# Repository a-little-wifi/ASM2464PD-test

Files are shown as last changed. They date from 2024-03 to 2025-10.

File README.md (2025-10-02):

# ASM2464PD-test
I wanted to know more about the new Asmedia USB4 chips because I want to make USB-C PCIe stuff.

The ASM2464PD is meant for USB4 (or Thunderbolt 3 and USB3.x too, afaik) to NVMe SSD enclosures, and the ASM2464PDX is meant for USB4/TB to general PCIe devices such as GPUs.  
I've read that the PD one also works for general PCIe devices but it's not officially supported. An AX210 wifi card worked on an ASM2464PD (non-X) enclosure for me, haven't tried GPUs yet.

So anyway I found some sussy data online and made a kicad version of the ASM2464PD pcb footprint and schematic symbol, it's a start to figuring out how to DIY something with these chips. I've got datasheets and reference schematics now so I'm slowly working on making a complete functional replica.  

Current PCB layout is only for fun, differential pairs are not impedance matched yet and there's probably various other issues lol. 

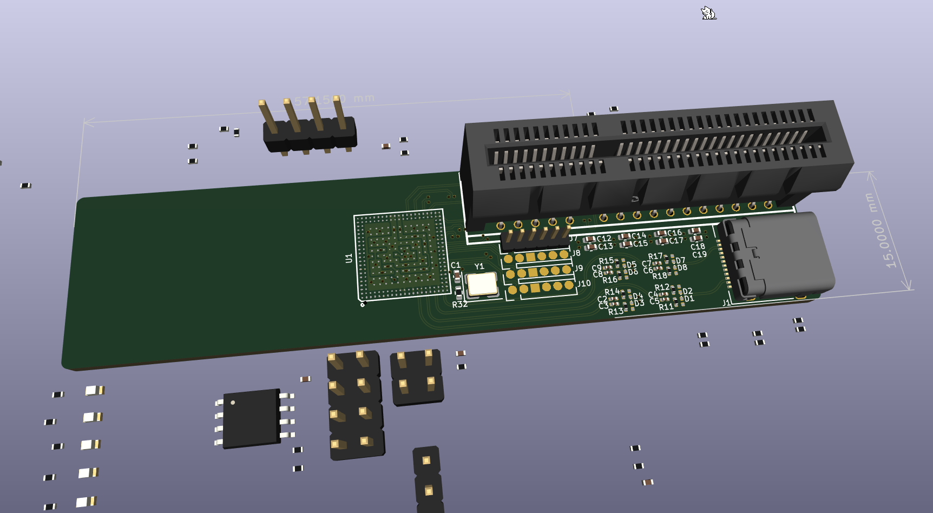
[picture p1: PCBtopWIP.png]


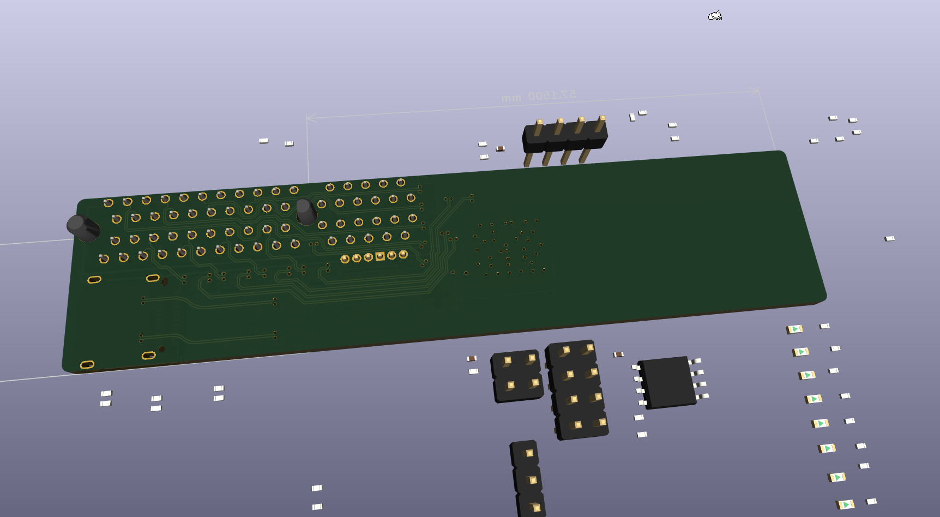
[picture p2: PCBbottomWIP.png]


Random Chinese forum link with datasheet screenshots + bits of a reference schematic: https://blog.csdn.net/weixin_54493972/article/details/127628081

Footprint/symbol reference: https://jlcpcb.com/partdetail/Asmedia-ASM2464PD/C7509569

Detailed images of a board: https://www.reddit.com/r/UsbCHardware/comments/17tjmh4/diy_ultra_compact_usb4thunderbolt_4_ssd_enclosure/

Datasheets and reference schematics: https://files.slop.gay/pub/docs/Asmedia/ASM2464PD-X/

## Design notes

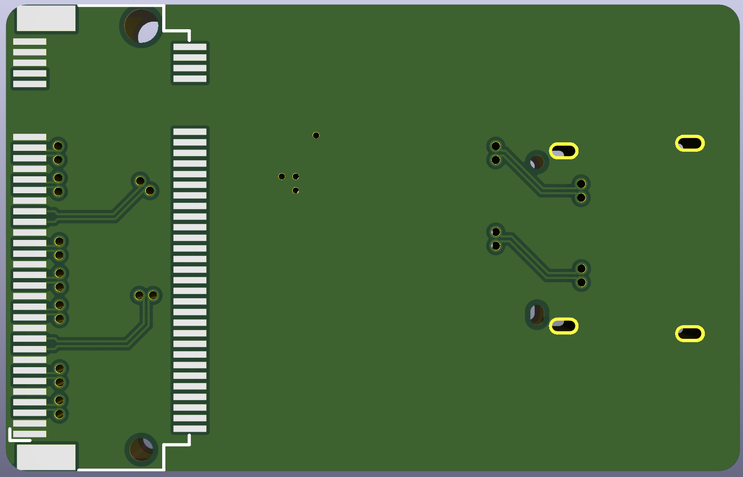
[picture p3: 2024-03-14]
PCBback.png

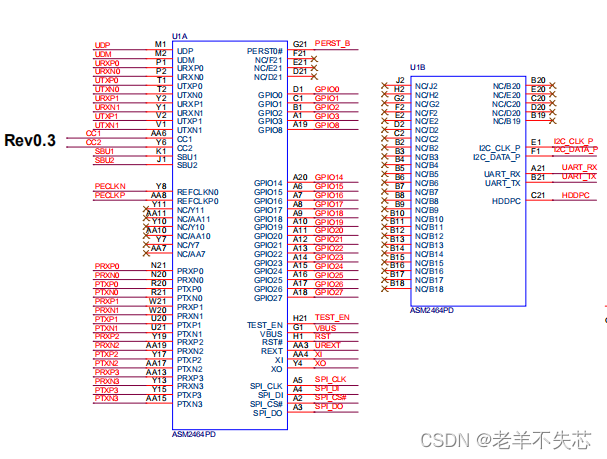
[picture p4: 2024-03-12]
ASM2464pins.png

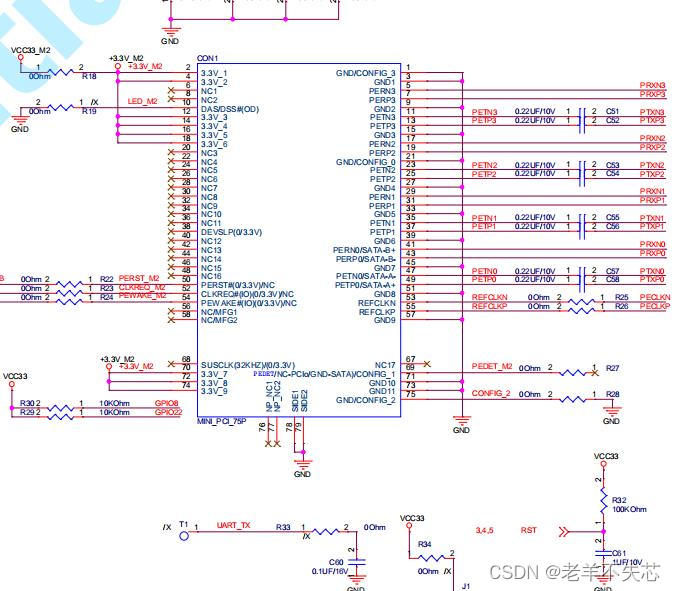
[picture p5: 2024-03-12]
M2pins.jpeg

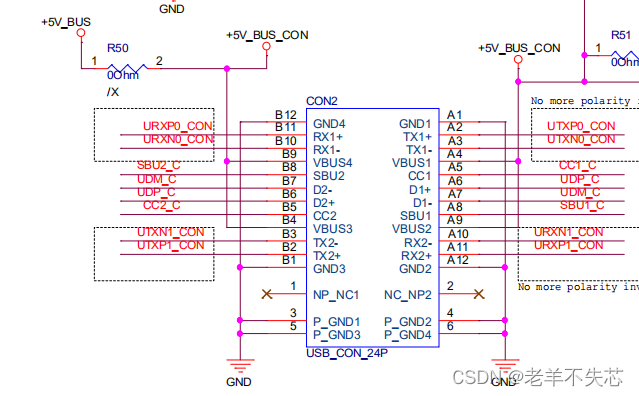
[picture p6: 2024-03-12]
USBCpins.png

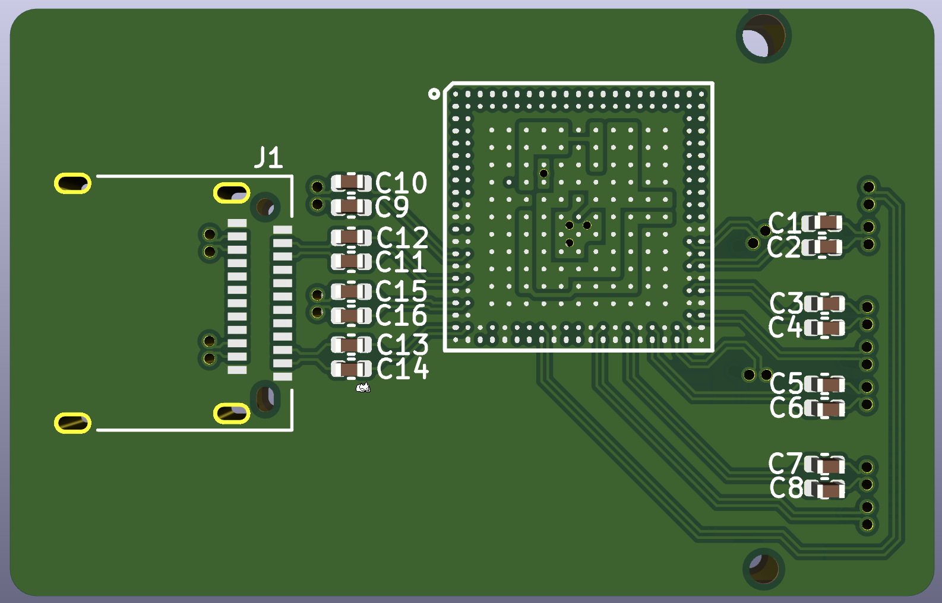
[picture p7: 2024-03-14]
PCBfront.png

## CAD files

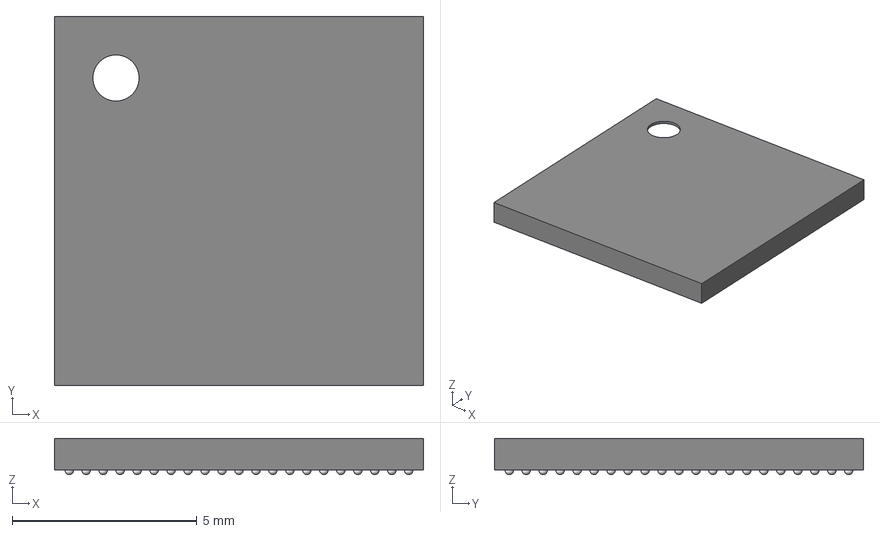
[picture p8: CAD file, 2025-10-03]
asm2464pd-kinda-close-enough.step
10.0 x 10.0 x 0.982 mm
ball x 377

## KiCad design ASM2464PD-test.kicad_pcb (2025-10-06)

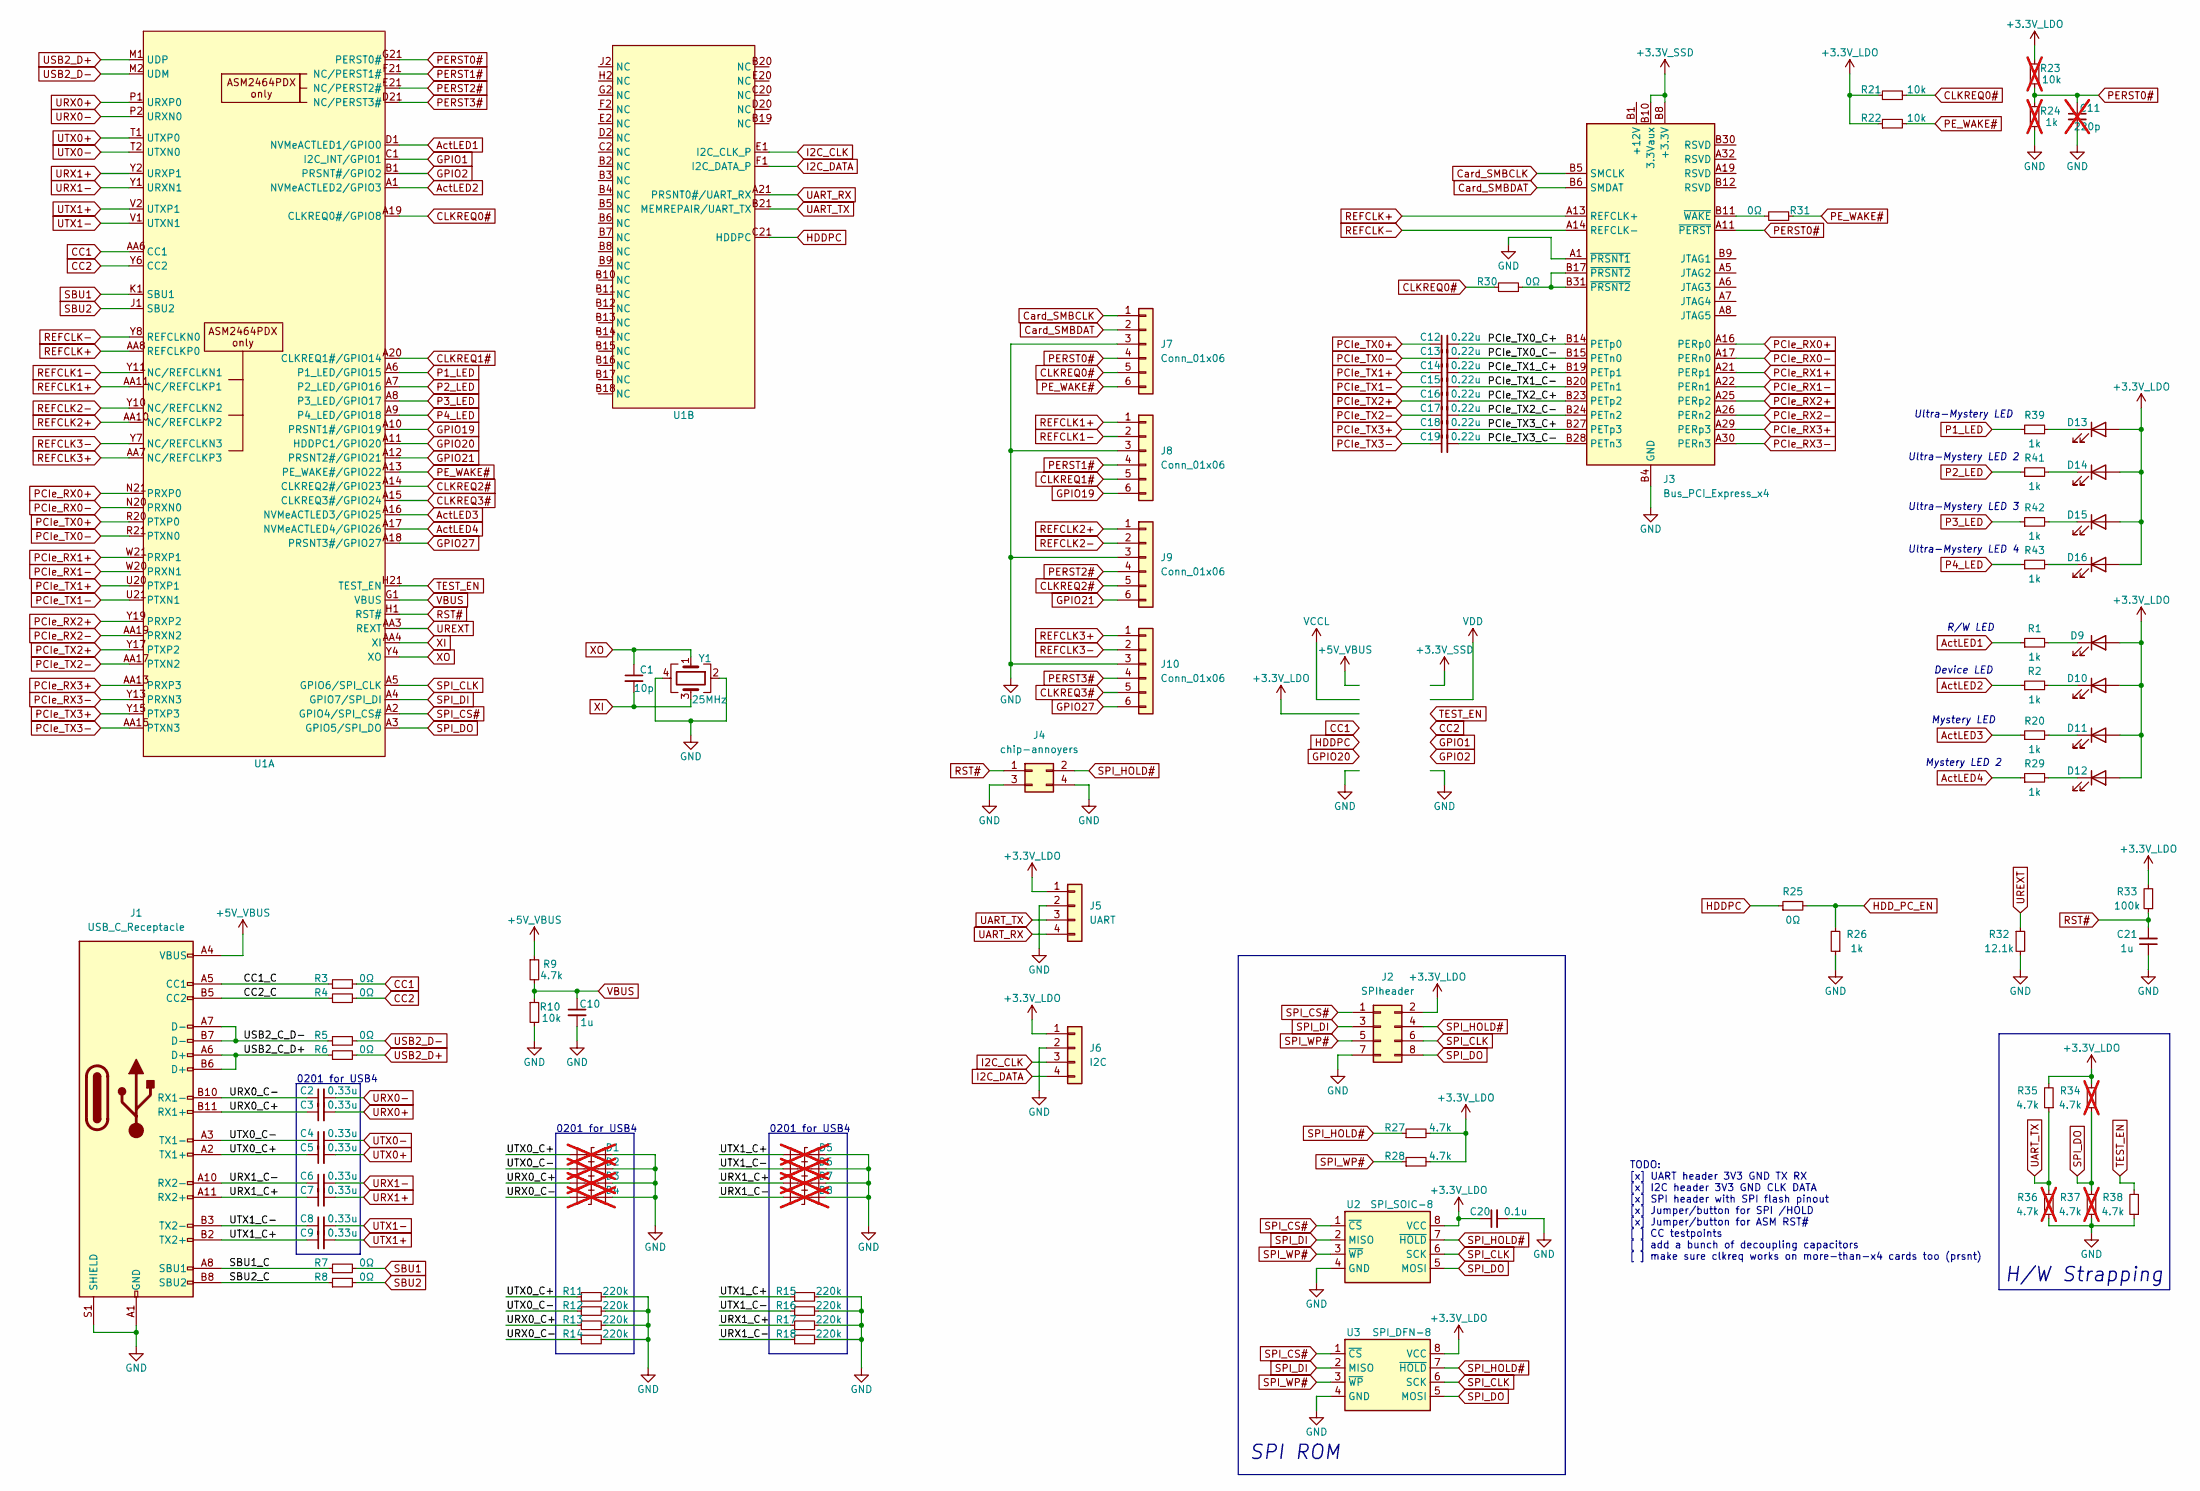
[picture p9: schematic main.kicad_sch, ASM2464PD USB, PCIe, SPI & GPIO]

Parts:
C1: 10p; C_0402_1005Metric
C2, C3, C4, C5, C6, C7, C8, C9: 0.33u; C_0201_0603Metric
C10, C21: 1u; C_0402_1005Metric
C11: 220p; C_0402_1005Metric; not fitted
C12, C13, C14, C15, C16, C17, C18, C19: 0.22u; C_0402_1005Metric
C20: 0.1u; C_0402_1005Metric
D1, D2, D3, D4, D5, D6, D7, D8: D_0201_0603Metric; not fitted
D9, D10, D11, D12, D13, D14, D15, D16: LED_0603_1608Metric
J1: USB_C_Receptacle; USB_C_Receptacle_Amphenol_12401610E4-2A
J2: SPIheader; PinHeader_2x04_P2.54mm_Vertical
J3: Bus_PCI_Express_x4; PCIe_x4_tht_open
J4: chip-annoyers; PinHeader_2x02_P2.54mm_Vertical
J5: UART; PinHeader_1x04_P2.54mm_Vertical
J6: I2C; PinHeader_1x04_P2.54mm_Vertical
J7, J8, J9, J10: Conn_01x06; PinHeader_1x06_P1.27mm_Vertical
R1, R2, R20, R26, R29, R39, R41, R42, R43: 1k; R_0402_1005Metric
R3, R4, R5, R6, R7, R8, R25, R30, R31: 0Ω; R_0402_1005Metric
R9, R27, R28, R35, R38: 4.7k; R_0402_1005Metric
R10, R21, R22: 10k; R_0402_1005Metric
R11, R12, R13, R14, R15, R16, R17, R18: 220k; R_0201_0603Metric
R23: 10k; R_0402_1005Metric; not fitted
R24: 1k; R_0402_1005Metric; not fitted
R32: 12.1k; R_0402_1005Metric
R33: 100k; R_0402_1005Metric
R34, R36, R37: 4.7k; R_0402_1005Metric; not fitted
U1: ASM2464PD
U2: SPI_SOIC-8; SOIC-8_5.3x5.3mm_P1.27mm
U3: SPI_DFN-8; DFN-8-1EP_3x2mm_P0.5mm_EP1.3x1.5mm
Y1: 25MHz; Crystal_SMD_3225-4Pin_3.2x2.5mm

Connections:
+3.3V_LDO: C20.1, D9.2 (A), D10.2 (A), D11.2 (A), D12.2 (A), D13.2 (A), D14.2 (A), D15.2 (A), D16.2 (A), J2.2, J5.1, J6.1, R21.1, R22.1, R23.1, R27.2, R28.2, R33.2, R34.2, R35.2, U2.8 (VCC), U3.8 (VCC); also elsewhere on the board
+3.3V_SSD: J3.A9 (+3.3V), J3.A10 (+3.3V), J3.B8 (+3.3V), J3.B10 (3.3Vaux)
+5V_VBUS: J1.A4 (VBUS), J1.A9 (VBUS), J1.B4 (VBUS), J1.B9 (VBUS), R9.1
/Main/CC1_C: J1.A5 (CC1), R3.1
/Main/CC2_C: J1.B5 (CC2), R4.1
/Main/PCIe_TX0_C+: C12.2, J3.B14 (PETp0)
/Main/PCIe_TX0_C-: C13.2, J3.B15 (PETn0)
/Main/PCIe_TX1_C+: C14.2, J3.B19 (PETp1)
/Main/PCIe_TX1_C-: C15.2, J3.B20 (PETn1)
/Main/PCIe_TX2_C+: C16.2, J3.B23 (PETp2)
/Main/PCIe_TX2_C-: C17.2, J3.B24 (PETn2)
/Main/PCIe_TX3_C+: C18.2, J3.B27 (PETp3)
/Main/PCIe_TX3_C-: C19.2, J3.B28 (PETn3)
/Main/SBU1_C: J1.A8 (SBU1), R7.1
/Main/SBU2_C: J1.B8 (SBU2), R8.1
/Main/URX0_C+: C3.1, D3.1 (A1), J1.B11 (RX1+), R13.1
/Main/URX0_C-: C2.1, D4.1 (A1), J1.B10 (RX1-), R14.1
/Main/URX1_C+: C7.1, D7.1 (A1), J1.A11 (RX2+), R17.1
/Main/URX1_C-: C6.1, D8.1 (A1), J1.A10 (RX2-), R18.1
/Main/USB2_C_D+: J1.A6 (D+), J1.B6 (D+), R6.1
/Main/USB2_C_D-: J1.A7 (D-), J1.B7 (D-), R5.1
/Main/UTX0_C+: C5.1, D1.1 (A1), J1.A2 (TX1+), R11.1
/Main/UTX0_C-: C4.1, D2.1 (A1), J1.A3 (TX1-), R12.1
/Main/UTX1_C+: C9.1, D5.1 (A1), J1.B2 (TX2+), R15.1
/Main/UTX1_C-: C8.1, D6.1 (A1), J1.B3 (TX2-), R16.1
ActLED1: R1.1, U1.D1 (NVMeACTLED1/GPIO0)
ActLED2: R2.1, U1.A1 (NVMeACTLED2/GPIO3)
ActLED3: R20.1, U1.A16 (NVMeACTLED3/GPIO25)
ActLED4: R29.1, U1.A17 (NVMeACTLED4/GPIO26)
CC1: R3.2, U1.AA6 (CC1)
CC2: R4.2, U1.Y6 (CC2)
CLKREQ0#: J7.5, R21.2, R30.1, U1.A19 (CLKREQ0#/GPIO8)
CLKREQ1#: J8.5, U1.A20 (CLKREQ1#/GPIO14)
CLKREQ2#: J9.5, U1.A14 (CLKREQ2#/GPIO23)
CLKREQ3#: J10.5, U1.A15 (CLKREQ3#/GPIO24)
Card_SMBCLK: J3.B5 (SMCLK), J7.1
Card_SMBDAT: J3.B6 (SMDAT), J7.2
GND: C10.2, C11.2, C20.2, C21.1, D1.2 (A2), D2.2 (A2), D3.2 (A2), D4.2 (A2), D5.2 (A2), D6.2 (A2), D7.2 (A2), D8.2 (A2), J1.A1 (GND), J1.A12 (GND), J1.B1 (GND), J1.B12 (GND), J1.S1 (SHIELD), J2.7, J3.A1 (~PRSNT1), J3.A4 (GND), J3.A12 (GND), J3.A15 (GND), J3.A18 (GND), J3.A20 (GND), J3.A23 (GND), J3.A24 (GND), J3.A27 (GND), J3.A28 (GND), J3.A31 (GND), J3.B4 (GND), J3.B7 (GND), J3.B13 (GND), J3.B16 (GND), J3.B18 (GND), J3.B21 (GND), J3.B22 (GND), J3.B25 (GND), J3.B26 (GND), J3.B29 (GND), J3.B32 (GND), J4.3, J4.4, J5.2, J6.2, J7.3, J8.3, J9.3, J10.3, R10.2, R11.2, R12.2, R13.2, R14.2, R15.2, R16.2, R17.2, R18.2, R24.2, R26.1, R32.2, R36.1, R37.1, R38.1, U2.4 (GND), U3.4 (GND), Y1.2, Y1.4; also elsewhere on the board
GPIO1: U1.C1 (I2C_INT/GPIO1)
GPIO2: U1.B1 (PRSNT#/GPIO2)
GPIO19: J8.6, U1.A10 (PRSNT1#/GPIO19)
GPIO20: U1.A11 (HDDPC1/GPIO20)
GPIO21: J9.6, U1.A12 (PRSNT2#/GPIO21)
GPIO27: J10.6, U1.A18 (PRSNT3#/GPIO27)
HDDPC: R25.1, U1.C21 (HDDPC)
HDD_PC_EN: R25.2, R26.2
I2C_CLK: J6.3, U1.E1 (I2C_CLK_P)
I2C_DATA: J6.4, U1.F1 (I2C_DATA_P)
unnamed: D9.1 (K), R1.2
unnamed: D10.1 (K), R2.2
unnamed: D11.1 (K), R20.2
unnamed: D12.1 (K), R29.2
unnamed: D13.1 (K), R39.2
unnamed: D14.1 (K), R41.2
unnamed: D15.1 (K), R42.2
unnamed: D16.1 (K), R43.2
unnamed: J3.A2 (+12V), J3.A3 (+12V), J3.B1 (+12V), J3.B2 (+12V), J3.B3 (+12V)
unnamed: J3.B17 (~PRSNT2), J3.B31 (~PRSNT2), R30.2
unnamed: J3.B11 (~WAKE), R31.2
P1_LED: R39.1, U1.A6 (P1_LED/GPIO15)
P2_LED: R41.1, U1.A7 (P2_LED/GPIO16)
P3_LED: R42.1, U1.A8 (P3_LED/GPIO17)
P4_LED: R43.1, U1.A9 (P4_LED/GPIO18)
PCIe_RX0+: J3.A16 (PERp0), U1.N21 (PRXP0)
PCIe_RX0-: J3.A17 (PERn0), U1.N20 (PRXN0)
PCIe_RX1+: J3.A21 (PERp1), U1.W21 (PRXP1)
PCIe_RX1-: J3.A22 (PERn1), U1.W20 (PRXN1)
PCIe_RX2+: J3.A25 (PERp2), U1.Y19 (PRXP2)
PCIe_RX2-: J3.A26 (PERn2), U1.AA19 (PRXN2)
PCIe_RX3+: J3.A29 (PERp3), U1.AA13 (PRXP3)
PCIe_RX3-: J3.A30 (PERn3), U1.Y13 (PRXN3)
PCIe_TX0+: C12.1, U1.R20 (PTXP0)
PCIe_TX0-: C13.1, U1.R21 (PTXN0)
PCIe_TX1+: C14.1, U1.U20 (PTXP1)
PCIe_TX1-: C15.1, U1.U21 (PTXN1)
PCIe_TX2+: C16.1, U1.Y17 (PTXP2)
PCIe_TX2-: C17.1, U1.AA17 (PTXN2)
PCIe_TX3+: C18.1, U1.Y15 (PTXP3)
PCIe_TX3-: C19.1, U1.AA15 (PTXN3)
PERST0#: C11.1, J3.A11 (~PERST), J7.4, R23.2, R24.1, U1.G21 (PERST0#)
PERST1#: J8.4, U1.F21 (NC/PERST1#)
PERST2#: J9.4, U1.E21 (NC/PERST2#)
PERST3#: J10.4, U1.D21 (NC/PERST3#)
PE_WAKE#: J7.6, R22.2, R31.1, U1.A13 (PE_WAKE#/GPIO22)
REFCLK1+: J8.1, U1.AA11 (NC/REFCLKP1)
REFCLK1-: J8.2, U1.Y11 (NC/REFCLKN1)
REFCLK2+: J9.1, U1.AA10 (NC/REFCLKP2)
REFCLK2-: J9.2, U1.Y10 (NC/REFCLKN2)
REFCLK3+: J10.1, U1.AA7 (NC/REFCLKP3)
REFCLK3-: J10.2, U1.Y7 (NC/REFCLKN3)
REFCLK+: J3.A13 (REFCLK+), U1.AA8 (REFCLKP0)
REFCLK-: J3.A14 (REFCLK-), U1.Y8 (REFCLKN0)
RST#: C21.2, J4.1, R33.1, U1.H1 (RST#)
SBU1: R7.2, U1.K1 (SBU1)
SBU2: R8.2, U1.J1 (SBU2)
SPI_CLK: J2.6, U1.A5 (GPIO6/SPI_CLK), U2.6 (SCK), U3.6 (SCK)
SPI_CS#: J2.1, U1.A2 (GPIO4/SPI_CS#), U2.1 (~CS), U3.1 (~CS)
SPI_DI: J2.3, U1.A4 (GPIO7/SPI_DI), U2.2 (MISO), U3.2 (MISO)
SPI_DO: J2.8, R34.1, R37.2, U1.A3 (GPIO5/SPI_DO), U2.5 (MOSI), U3.5 (MOSI)
SPI_HOLD#: J2.4, J4.2, R27.1, U2.7 (~HOLD), U3.7 (~HOLD)
SPI_WP#: J2.5, R28.1, U2.3 (~WP), U3.3 (~WP)
TEST_EN: R38.2, U1.H21 (TEST_EN)
UART_RX: J5.4, U1.A21 (PRSNT0#/UART_RX)
UART_TX: J5.3, R35.1, R36.2, U1.B21 (MEMREPAIR/UART_TX)
UREXT: R32.1, U1.AA3 (REXT)
URX0+: C3.2, U1.P1 (URXP0)
URX0-: C2.2, U1.P2 (URXN0)
URX1+: C7.2, U1.Y2 (URXP1)
URX1-: C6.2, U1.Y1 (URXN1)
USB2_D+: R6.2, U1.M1 (UDP)
USB2_D-: R5.2, U1.M2 (UDM)
UTX0+: C5.2, U1.T1 (UTXP0)
UTX0-: C4.2, U1.T2 (UTXN0)
UTX1+: C9.2, U1.V2 (UTXP1)
UTX1-: C8.2, U1.V1 (UTXN1)
VBUS: C10.1, R9.2, R10.1, U1.G1 (VBUS)
XI: C1.2, U1.AA4 (XI), Y1.3
XO: C1.1, U1.Y4 (XO), Y1.1

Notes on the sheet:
0201 for USB4
Mystery LED 2
H/W Strapping
Ultra-Mystery LED 2
TODO: [x] UART header 3V3 GND TX RX [x] I2C header 3V3 GND CLK DATA [x] SPI header with SPI flash pinout [x] Jumper/button for SPI /HOLD [x] Jumper/button for ASM RST# [ ] CC testpoints [ ] add a bunch of decoupling capacitors [ ] make sure clkreq works on more-than-x4 cards too (prsnt)
Device LED
R/W LED
Mystery LED
Ultra-Mystery LED
Ultra-Mystery LED 3
SPI ROM
Ultra-Mystery LED 4

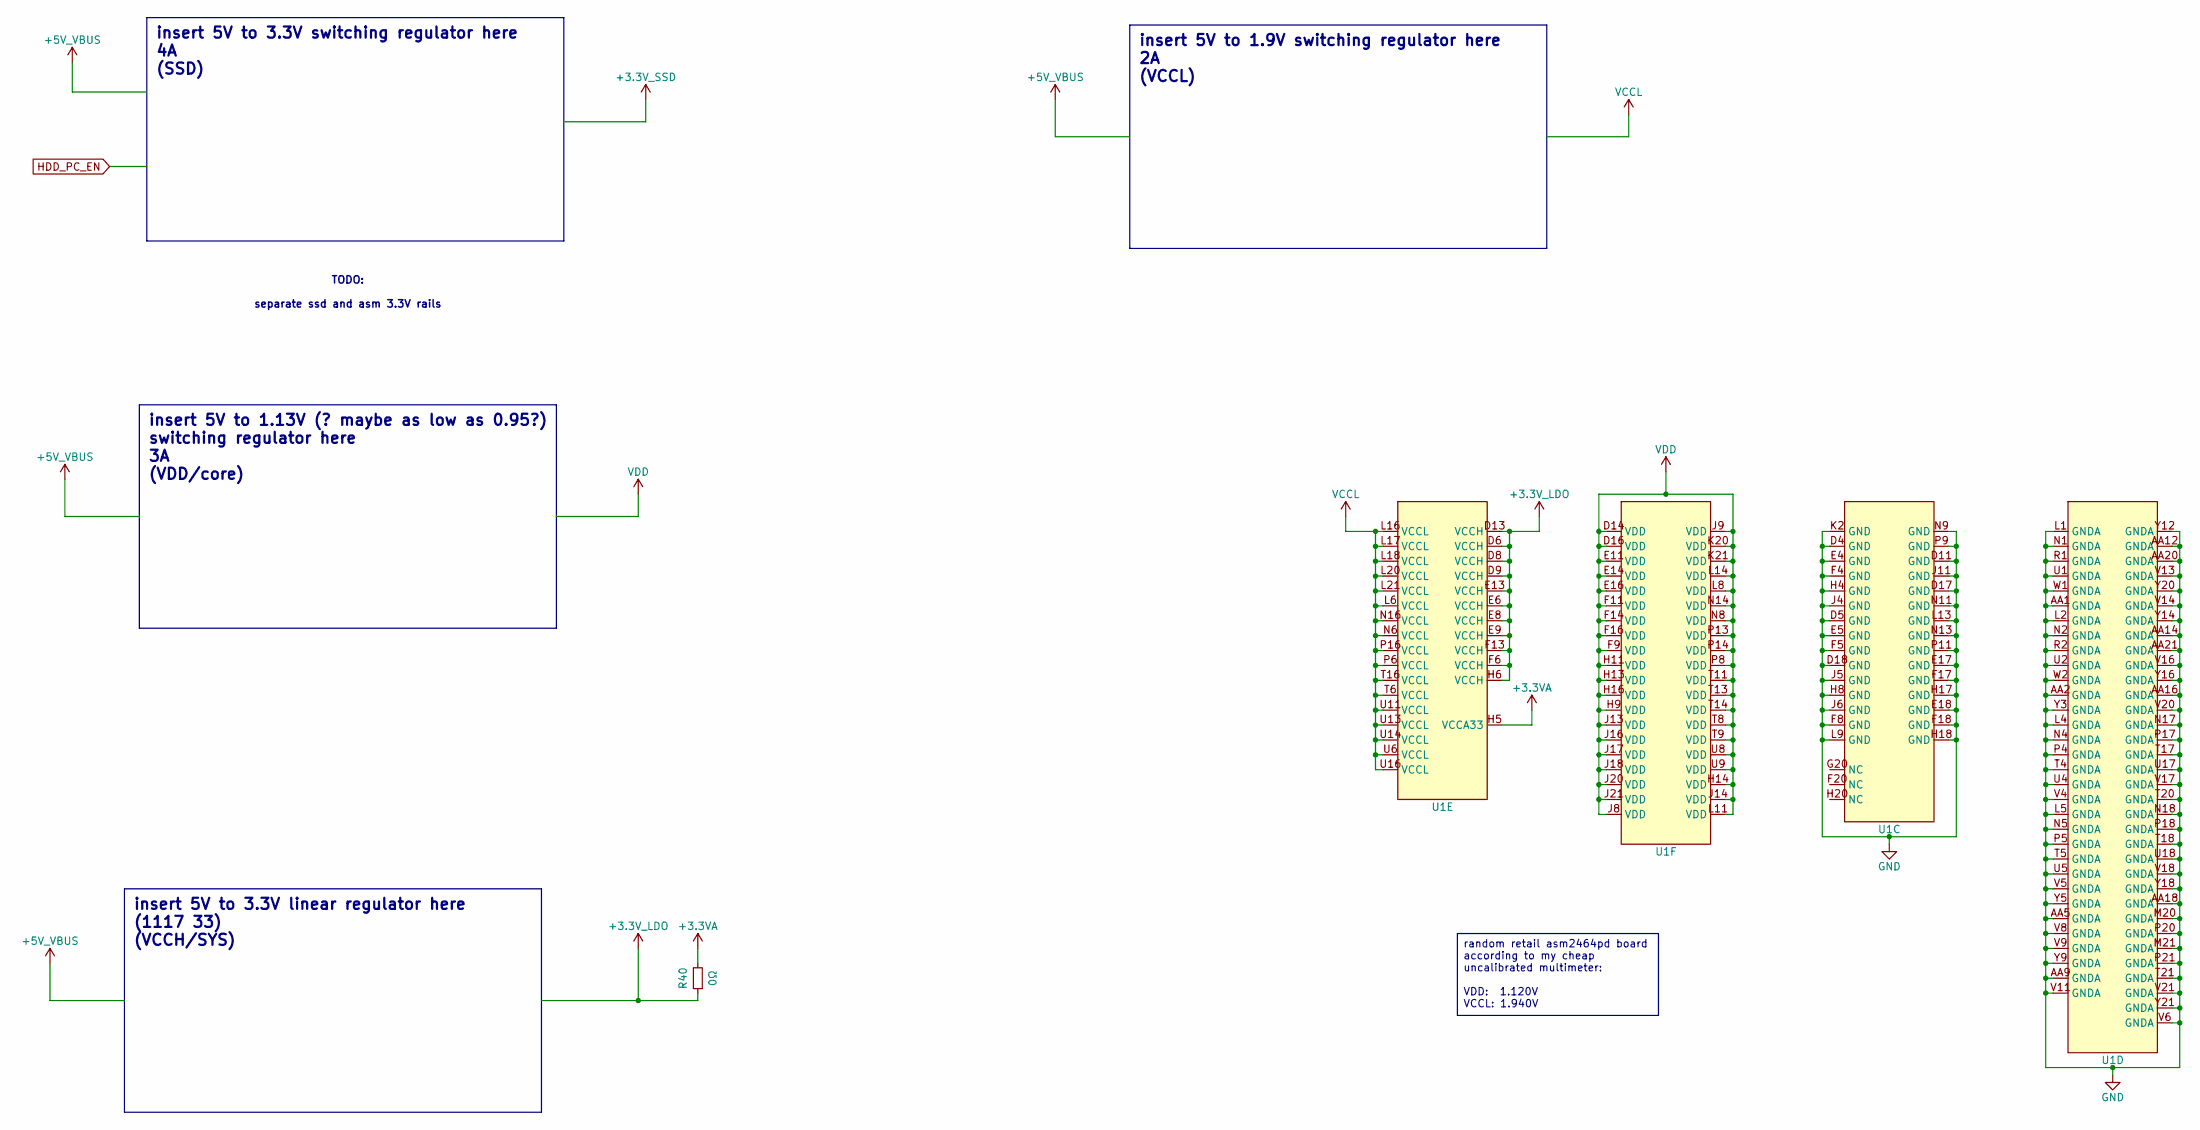
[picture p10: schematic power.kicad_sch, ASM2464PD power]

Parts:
R40: 0Ω; R_0402_1005Metric
U1: ASM2464PD

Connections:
+3.3VA: R40.2, U1.H5 (VCCA33)
+3.3V_LDO: R40.1, U1.D6 (VCCH), U1.D8 (VCCH), U1.D9 (VCCH), U1.D13 (VCCH), U1.E6 (VCCH), U1.E8 (VCCH), U1.E9 (VCCH), U1.E13 (VCCH), U1.F6 (VCCH), U1.F13 (VCCH), U1.H6 (VCCH); also elsewhere on the board
GND: U1.AA1 (GNDA), U1.AA2 (GNDA), U1.AA5 (GNDA), U1.AA9 (GNDA), U1.AA12 (GNDA), U1.AA14 (GNDA), U1.AA16 (GNDA), U1.AA18 (GNDA), U1.AA20 (GNDA), U1.AA21 (GNDA), U1.D4 (GND), U1.D5 (GND), U1.D11 (GND), U1.D17 (GND), U1.D18 (GND), U1.E4 (GND), U1.E5 (GND), U1.E17 (GND), U1.E18 (GND), U1.F4 (GND), U1.F5 (GND), U1.F8 (GND), U1.F17 (GND), U1.F18 (GND), U1.H4 (GND), U1.H8 (GND), U1.H17 (GND), U1.H18 (GND), U1.J4 (GND), U1.J5 (GND), U1.J6 (GND), U1.J11 (GND), U1.K2 (GND), U1.L1 (GNDA), U1.L2 (GNDA), U1.L4 (GNDA), U1.L5 (GNDA), U1.L9 (GND), U1.L13 (GND), U1.M20 (GNDA), U1.M21 (GNDA), U1.N1 (GNDA), U1.N2 (GNDA), U1.N4 (GNDA), U1.N5 (GNDA), U1.N9 (GND), U1.N11 (GND), U1.N13 (GND), U1.N17 (GNDA), U1.N18 (GNDA), U1.P4 (GNDA), U1.P5 (GNDA), U1.P9 (GND), U1.P11 (GND), U1.P17 (GNDA), U1.P18 (GNDA), U1.P20 (GNDA), U1.P21 (GNDA), U1.R1 (GNDA), U1.R2 (GNDA), U1.T4 (GNDA), U1.T5 (GNDA), U1.T17 (GNDA), U1.T18 (GNDA), U1.T20 (GNDA), U1.T21 (GNDA), U1.U1 (GNDA), U1.U2 (GNDA), U1.U4 (GNDA), U1.U5 (GNDA), U1.U17 (GNDA), U1.U18 (GNDA), U1.V4 (GNDA), U1.V5 (GNDA), U1.V6 (GNDA), U1.V8 (GNDA), U1.V9 (GNDA), U1.V11 (GNDA), U1.V13 (GNDA), U1.V14 (GNDA), U1.V16 (GNDA), U1.V17 (GNDA), U1.V18 (GNDA), U1.V20 (GNDA), U1.V21 (GNDA), U1.W1 (GNDA), U1.W2 (GNDA), U1.Y3 (GNDA), U1.Y5 (GNDA), U1.Y9 (GNDA), U1.Y12 (GNDA), U1.Y14 (GNDA), U1.Y16 (GNDA), U1.Y18 (GNDA), U1.Y20 (GNDA), U1.Y21 (GNDA); also elsewhere on the board
VCCL: U1.L6 (VCCL), U1.L16 (VCCL), U1.L17 (VCCL), U1.L18 (VCCL), U1.L20 (VCCL), U1.L21 (VCCL), U1.N6 (VCCL), U1.N16 (VCCL), U1.P6 (VCCL), U1.P16 (VCCL), U1.T6 (VCCL), U1.T16 (VCCL), U1.U6 (VCCL), U1.U11 (VCCL), U1.U13 (VCCL), U1.U14 (VCCL), U1.U16 (VCCL)
VDD: U1.D14 (VDD), U1.D16 (VDD), U1.E11 (VDD), U1.E14 (VDD), U1.E16 (VDD), U1.F9 (VDD), U1.F11 (VDD), U1.F14 (VDD), U1.F16 (VDD), U1.H9 (VDD), U1.H11 (VDD), U1.H13 (VDD), U1.H14 (VDD), U1.H16 (VDD), U1.J8 (VDD), U1.J9 (VDD), U1.J13 (VDD), U1.J14 (VDD), U1.J16 (VDD), U1.J17 (VDD), U1.J18 (VDD), U1.J20 (VDD), U1.J21 (VDD), U1.K20 (VDD), U1.K21 (VDD), U1.L8 (VDD), U1.L11 (VDD), U1.L14 (VDD), U1.N8 (VDD), U1.N14 (VDD), U1.P8 (VDD), U1.P13 (VDD), U1.P14 (VDD), U1.T8 (VDD), U1.T9 (VDD), U1.T11 (VDD), U1.T13 (VDD), U1.T14 (VDD), U1.U8 (VDD), U1.U9 (VDD)

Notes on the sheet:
TODO: separate ssd and asm 3.3V rails
insert 5V to 1.13V (? maybe as low as 0.95?) switching regulator here 3A (VDD/core)
insert 5V to 1.9V switching regulator here 2A (VCCL)
insert 5V to 3.3V switching regulator here 4A (SSD)
insert 5V to 3.3V linear regulator here (1117 33) (VCCH/SYS)
random retail asm2464pd board according to my cheap uncalibrated multimeter: VDD: 1.120V VCCL: 1.940V

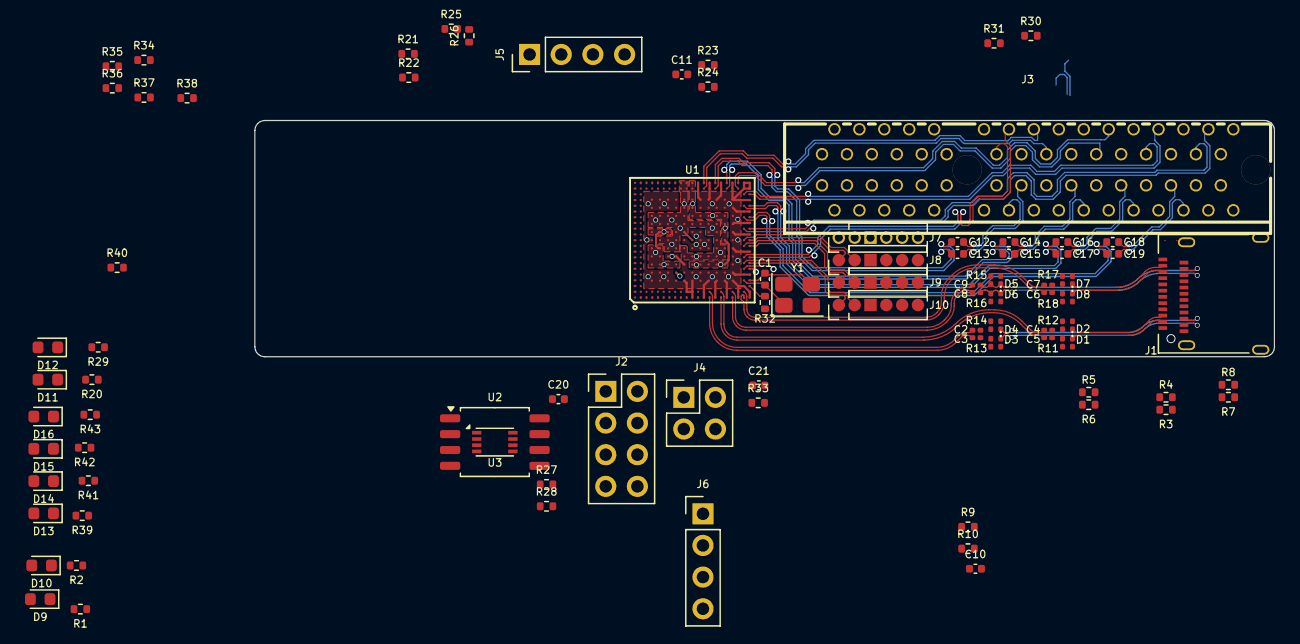
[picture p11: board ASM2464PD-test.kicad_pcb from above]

Board: 4 copper layers, 81.8 x 19.0 mm, 93 parts (0 on the bottom side), 118 nets.

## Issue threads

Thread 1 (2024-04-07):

If you are interested, please contact me

xuexuedan, 2024-04-07:
I have official schematic diagrams and data manuals here. If needed, I can provide them to you.

xuexuedan, 2024-04-07:
Leave your email and I will send it to you.

a-little-wifi, 2024-04-07:
Oh hey that would be amazing, I'd love to have those. Here's an email you can send it to: alittlesecret24@gmail.com
Thanks a lot!

a-little-wifi, 2024-04-07:
Wait, nevermind, I just got locked out of that account lol. I guess making a throwaway gmail account isn't that easy. Can you do alittlesecret24@protonmail.com instead?

xuexuedan, 2024-04-07:
Sent, received.

a-little-wifi, 2024-04-07:
Received, thank you very much, these will be very useful. I'll try to continue the design in this repository using it.
I am wondering, do you have the documents for the ASM2464PDX version as well?

xuexuedan, 2024-04-07:
The information for asm2464PDX is currently unavailable. If needed, I can ask the manufacturer for it, but it will take time to wait.

a-little-wifi, 2024-04-07:
I see. It would be cool to have for possible future use, not needed immediately so it's ok if it takes some time.
In the mean time I have a question: Is it ok for me to share these documents with other people or upload them somewhere? I won't if it would get you in trouble or something but if it is possible I think it would be good if the information was out there.

xuexuedan, 2024-04-07:
It's okay, it can be shared with anyone

xuexuedan, 2024-04-07:
The information for ASM3074C USB-C 3.2 20G HUB will also be sent to you later, hoping it will be helpful to you.This chip is not for sale, so it needs to be kept confidential until after August 16, 2024

xuexuedan, 2024-04-08:
The information for asm2464pdx has been sent via email.

a-little-wifi, 2024-04-08:
Hi, sorry for not getting back earlier, was a bit busy. Not sure why your messages are gone. Thank you very much for the ASM2464PDX information, I'll try to make good use of that too. The ASM3074C sounds interesting too, I have no problem keeping that confidential until august 16th.

xuexuedan, 2024-04-09:
Enjoy.

traikovich2, 2024-06-10:
Hi, I am also interested in the ASM2464PD/ASM2464PDX datasheet and reference schematics. If it is possible, can you send these materials to my e-mail address (rt984984@gmail.com)? I would very appreciate it.

a-little-wifi, 2024-06-10:
Hi, sure I can send them to you.
If anyone else is interested, feel free to ask by the way. Unfortunately I don't have an accessible place to upload them without trouble but I'll gladly email them.

rainonatinroof, 2024-09-14:
Hi @a-little-wifi , I'd really appreciate if you could email a copy of the ASM2464PD & PDX schematics + supporting documentation to me as well. My email is jim.witherspoon.perkin@gmail.com. I'm considering trying to use the ASM2464PD in a personal project but can't find enough info online to begin using it. Thanks in advance for your help!

a-little-wifi, 2024-09-14:
Sent!

Hyffer, 2025-02-17:
Hello @a-little-wifi, sorry to bother you. Could you also email me(gaohuyufan@gmail.com) a copy of ASM2464PDX datasheet? It would be even better if there exists verification board schematic and PCB layout, or something like that.

I am an amateur in electronic engineering, and only have some experience with STM32 development. ST just has there manual on their website for public access. I wonder why it is so hard to find datasheet and schematic of thunderbolt/USB4 related product (I also tried to search for manual of intel JHLxxxx chips, but no luck).

In any case, thanks for your help!

xuexuedan, 2025-02-17:
cooger
***@***.***

&nbsp;

------------------&nbsp;原始邮件&nbsp;------------------
发件人:                                                                                                                        "a-little-wifi/ASM2464PD-test"                                                                                    ***@***.***&gt;;
发送时间:&nbsp;2025年2月17日(星期一) 晚上8:10
***@***.***&gt;;
***@***.******@***.***&gt;;
主题:&nbsp;Re: [a-little-wifi/ASM2464PD-test]  If you are interested, please contact me (Issue #1)

Hello @a-little-wifi, sorry to bother you. Could you also email ***@***.***) a copy of ASM2464PDX datasheet? It would be even better if there exists verification board schematic and PCB layout, or something like that.

I am an amateur in electronic engineering, and only have some experience with STM32 development. ST just has there manual on their website for public access. I wonder why it is so hard to find datasheet and schematic of thunderbolt/USB4 related product (I also tried to search for manual of intel JHLxxxx chips, but no luck).

In any case, thanks for your help!

—
Reply to this email directly, view it on GitHub, or unsubscribe.
You are receiving this because you authored the thread.Message ID: ***@***.***&gt;
  Hyffer left a comment (a-little-wifi/ASM2464PD-test#1)

Hello @a-little-wifi, sorry to bother you. Could you also email ***@***.***) a copy of ASM2464PDX datasheet? It would be even better if there exists verification board schematic and PCB layout, or something like that.

I am an amateur in electronic engineering, and only have some experience with STM32 development. ST just has there manual on their website for public access. I wonder why it is so hard to find datasheet and schematic of thunderbolt/USB4 related product (I also tried to search for manual of intel JHLxxxx chips, but no luck).

In any case, thanks for your help!

—
Reply to this email directly, view it on GitHub, or unsubscribe.
You are receiving this because you authored the thread.Message ID: ***@***.***&gt;

TheElectricalEngineer25, 2025-05-24:
Hi @a-little-wifi, I'm also trying to build some DIY Thunderbolt/USB4 devices. Any info, datasheets, etc. you could share on the ASM2464PD/ASM2464PDX would be super helpful! Thanks in advance! theelectricalengineer@protonmail.com

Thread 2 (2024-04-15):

I haven't been busy lately, trying to complete the layout, but I seem to have encountered some problems.

xuexuedan, 2024-04-15:
My design seems to be almost completed, but it is obvious that the layout is very unreasonable, and many components cannot be placed, which is very troublesome for me.
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

a-little-wifi, 2024-04-15:
Hi, nice work, I didn't know you were also making one.
I'm not sure what your question is, are you looking for advice on fitting all the components on the board? It seems to be about as big as what I'm working on and the board pictured in the reddit post I linked.
You'll have to put a lot of the components under the space where the ssd will go, looks like there's still a lot of empty space there.
The USB-C port you're using also looks quite unusually large and the routing from it to the ASM2464 takes up a lot of space. Maybe it can be swapped with a port that takes up less space.

xuexuedan, 2024-04-16:
I am about to complete the layout, but it seems that I still need to do 3D modeling to verify the thickness and ensure the placement of SSD.

a-little-wifi, 2024-04-16:
Ah, yeah you're definitely gonna need to leave some space between the ssd and the board to place components there. I guess there's a lot of options for the height of the m.2 slot you use.

xuexuedan, 2024-04-16:
The ASM2464PD layout is completed and has been sent to the factory. The goal for next week is to complete the layout of ASM3074C.
For convenience, I will use easyeda to complete 3074, and perhaps I can share project files to assist in completing it.

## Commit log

2024-03-12 Added project files
    [ASM2464PD-test.kicad_pcb, ASM2464PD-test.kicad_sch]
2024-03-12 Connected the 2 grounds
    what's the difference anyway
    [ASM2464PD-test.kicad_pcb, ASM2464PD-test.kicad_sch]
2024-03-12 Added some keywords to readme
    [ASM2464PD-test.kicad_pcb, ASM2464PD-test.kicad_sch]
2024-03-12 Added ports and definitely didn't clone reddit board lol
    [ASM2464PD-test.kicad_pcb, ASM2464PD-test.kicad_sch]
2024-03-14 Tried adding power fills under the chip
    [ASM2464PD-test.kicad_pcb, ASM2464PD-test.kicad_sch]
2024-03-14 Slightly moved a diffpair
    [ASM2464PD-test.kicad_pcb]
2024-03-14 Updated PCB pics
    don't mind the cat
2024-03-14 forgor some power pins
    [ASM2464PD-test.kicad_pcb, ASM2464PD-test.kicad_sch]
2024-03-16 slightly moved a pair lol
    [ASM2464PD-test.kicad_pcb]
2024-04-05 Labeled power rails, upgraded to KiCad 8
    [ASM2464PD-test.kicad_pcb, ASM2464PD-test.kicad_sch]
2024-04-14 Updated symbol to match reference schematic
    [ASM2464PD-test.kicad_pcb, ASM2464PD-test.kicad_sch]
2024-04-14 Updated schematic and rerouted some stuff
    [ASM2464PD-test.kicad_pcb, ASM2464PD-test.kicad_sch]
2024-04-14 Added SPI flash, probably some more stuff, and made pcb 4-layer
    [ASM2464PD-test.kicad_pcb, ASM2464PD-test.kicad_sch]
2024-04-14 Added lots of power rail vias under chip
    [ASM2464PD-test.kicad_pcb]
2024-04-15 reran the other 2 USB4 pairs too, placed esd stuff
    [ASM2464PD-test.kicad_pcb]
2024-04-15 Moved SPI flash footprint onto board
    [ASM2464PD-test.kicad_pcb]
2024-04-15 Removed stupid custom schematic drawing sheet that didn't even work lol
    [ASM2464PD-test.kicad_sch]
2024-04-26 Adjusted ground fill under bga
    [ASM2464PD-test.kicad_pcb]
2024-04-26 Bunch more stuff copied from reference schematic
    [ASM2464PD-test.kicad_sch]
2024-04-27 changed ground trace width to match footprint pads
    [ASM2464PD-test.kicad_pcb]
2024-08-06 more schematic work
    [ASM2464PD-test.kicad_sch]
2024-08-15 Updated power rails
    [main.kicad_sch, power.kicad_sch]
2024-09-15 Updated outdate readme mentioning lack of info
    I already got the datasheets and schematics a while ago but never updated the readme....
2024-10-13 Added todo list
    [ASM2464PD-test.kicad_sch, main.kicad_sch, power.kicad_sch]
2025-09-22 Changing from M.2 adapter to PCIe x4 adapter
    I don't actually want an ssd enclosure, I want a PCIe-slot-giver for my laptop
    [ASM2464PD-test.kicad_pcb, ASM2464PD-test.kicad_sch, main.kicad_sch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]
2025-09-26 Added link to datasheets and reference schematics to readme + some other changes I forgot what I did lol
    thanks @mothenjoyer69 for hosting them!
    [ASM2464PD-test.kicad_pcb]
2025-09-29 Cleaning up schematic a bit
    Directly copying the reference schematic was stupid lol, what a mess
    [ASM2464PD-test.kicad_sch, main.kicad_sch, power.kicad_sch]
2025-09-29 power notes
    [ASM2464PD-test.kicad_pcb, main.kicad_sch, power.kicad_sch]
2025-09-30 Added function names to gpio pins
    [main.kicad_sch, power.kicad_sch]
2025-09-30 more pin names, more schematic cleanup, added SPI header
    baby I don't know when I'm supposed to stop (I should go to bed)
    [ASM2464PD-test.kicad_pcb, main.kicad_sch, power.kicad_sch]
2025-09-30 Very bad routing lol
    should probably not try to make it *that* compact
    [ASM2464PD-test.kicad_pcb, main.kicad_sch]
2025-09-30 component arrangement
    [ASM2464PD-test.kicad_pcb, main.kicad_sch, power.kicad_sch]
2025-10-02 A loooot of cool routing and added more connectors
    [ASM2464PD-test.kicad_pcb, main.kicad_sch]
2025-10-02 Horrible nightmare routing
    oh my stars will it do gen 4?
    [ASM2464PD-test.kicad_pcb, main.kicad_sch]
2025-10-02 Connected all the pcie lanes
    this fit together way too well lol, how even
    [ASM2464PD-test.kicad_pcb]
2025-10-02 Updated readme with new pictures
    [ASM2464PD-test.kicad_pcb]
2025-10-02 Made some space for future 12V supply trace
    [ASM2464PD-test.kicad_pcb]
2025-10-03 some notes
    [ASM2464PD-test.kicad_pcb, main.kicad_sch]
2025-10-03 Added ASM2464PD 3D model
    yoinked from here, thanks https://github.com/Leaves232/2230-USB4-SSD-Enclosure-Design
    [ASM2464PD-test.kicad_pcb, asm2464pd-kinda-close-enough.step, main.kicad_sch]
2025-10-06 Adjusted fills under asm2464pd a bit
    [ASM2464PD-test.kicad_pcb]
